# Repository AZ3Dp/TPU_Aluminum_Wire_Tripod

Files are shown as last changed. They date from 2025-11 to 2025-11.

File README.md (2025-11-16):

# FLEXPOD
#### TPU X ALU Wire Tripod
>By Aaron Zhan

Hello there! Thanks for stopping by!
## Introduction
I am a maker, 3D printer, inventor, and creative film-maker! 
(Though you can say those are a bit of a stretch, as I am learning new things almost every day). 
I tend to film Youtube videos with my phone, 
but I have always struggled to have a good yet simple camera/tripod setup. Mounting 
a camera is a struggle for anyone trying to take photos or videos (newbies and pros alike).
The main problem with tripods are that they aren't _flexible_ as int he sense that you can only use them in flat surfaces
and it is quite a hassle to adjust and set up (turning knobs, etc)
Luckily, the Gorilla Pod was invented. The Gorilla Pod (and other designs) feature 3 or more flexible
legs that can flex and adapt to the surface/object the tripod is to be mounted onto.
They are great products, and they are quite a hit!
However, if you are a fellew 3D printer, you would instantly have the instrusive thought of: "Can I 3D print that?"

Well, I tried that. And it went South. Some issues experienced with the Official Gorrila Pod was expereinced: 
the friction between the articulated links would gradually wear down. This would happen even whith the TPU bands around the links.
Well, there are variants of the gorilla pod where the legs are made out of 3 pieces of continuous metal that is flexible yet rigid
This design seldom loses its strength and thius its effectiveness. 
And with some inspiration from Reddit, I decided to make the tripod.
## Design Inspiration
So I had found a 3D printed Gorilla Pod design from My Mini Factory. It was honestly quite a clever design, taking great inspiration from the Original Gorilla Pid. It uses 3D printed segments in hard plastic (PLA, PETG, or ABS) and used some TPU connection parts (as "rubber bands" to connect and clamp down on the ball joints).
Again, worked _decently_, but after some extended use, the friction between the joints would wear down.
Luckily, I saw a reddit post: https://www.reddit.com/r/BambuLab/comments/1m8kska/aluminum_wire_in_tpu_is_my_new_favourite_thing_to/
and that gave me a lot of inspiration. I immediately saw some great insight in their design, and I thought I could make something amazing (even better) out of it. The designs mentioned in the Reddit post included many different uses, but being a content creator, I got excited at the sight of a tripod.
The Reddit user mentioned that 5mm craft wire was quite strong and flexible, so that's what I decided to go with. The Reddit user
also mentioned that stacking thin rectangular craft wires didn't cut it - it was too flimsy. This was perfect insight for me, since I didn't have to 
experiment with the different types of wire. The Reddit User's design uses a TPU print and embedding the wire into the TPU print. This is a clever 
way to accomplish the task, but it poses some problems that I identified: 1) The Aluminum Wire is not always straight and tidy, so embedding in the print may be
hard to accomplish and 2) If you want to remove the aluminum wire or swap it out for some reason, you'll have to destroy the TPU print. Embedding in the middle of the print job
is quite a hassle - bad for automation and user experience.
Screenshot 2025-11-09 at 11 44 03 AM
> The slits and 5mm hole enable a smooth experience when inserting and flexing the Aluminum Wire

## Design Innovation
And that's how my design was inspired and improved upon. FlexPod features easy-to-use TPU legs where you simply slide in the Aluminum Craft Wire (5mm, and generous tolerances were added!). This removes the hassle of pausing a print, making the process a whole lot easier! In addition, the leg takes advantage of the Pythagorean Theorem to be oriented on the build plate - you can get a 300mm long TPU leg out of a 220x200mm build plate! Some future plans include making an even longer TPU sleeve - possible oriented in a spiral - for those that need extra long tripod legs. The TPU 3D printed sleeves feature a repeating "slit" pattern, which alleviates stress and enables the TPU to be more flexible (and comply with the bending Aluminum Wire). These slits also reduce friction, enhancing the assembly process. For mounting, I included a simple m5 screw that is secured from the underside of the tripod. I know that people may have different variations of screws available, so the .f3d and .step files are included! m3 screws are used to mount the legs onto the base. The simplicity of the design is good to note! As for the model, I created a phone clamp that was remixed from a popular (and in my opinion, the best) phone clamp: https://www.printables.com/model/25969-tripod-mobile-phone-clamp-v2
Screenshot 2025-11-08 at 9 48 06 AM
> TinkerCAD is (sometimes) better than Fusion at _simple_ tasks!

###### lol a remix of a remix
So I simply took the base of that model, and combined it with the "base" of my Tripod in TinkerCAD (TinkerCAD is better at doing simple operations on STLs - you can do this in Slicer software as well).

## Materials Needed
I know there is a BOM, but this is probably more helpful
- Aluminum Wire
- m5 nuts and screws
- m3 nuts and screws
- TPU & PLA (or other rigid filament) for 3D printing

## Assembly and Manufacturing
FlexPod only has 5-7 printed parts in total (depending on how complicated the phone/camera/object mount is)
- 3 Legs: 95A (what I used, but more flexible is fine) TPU filament, 0.2mm (or finer) layer height, 2 perimeters, 15% infill
- Lower & Upper Base: PLA/ABS/PETG (rigid filament, PLA works fine), 0.2mm (or finer) layer height, 2 perimeters, 15% infill
- Mount (for camera, phone, etc): Make this as strong/weak as you want (depends on the application! For my phone clamp, I just used the same settings as above)

Assembly is pretty simple:
1) Insert the Aluminum Wire into the TPU sleeves, and use wire cutters to slowly (twisting the wire cutters for each cut) sever the Aluminum Wire
2) Prepare the bottom base: insert the m5 nut into the underside of the base. Screw in a m5 screw (I think m5x16 will do, depends on your application!) from the bottom
3) Insert m3 nuts into their respective slots on the bottom base. Fasten each leg to the base
4) Slide in a m5 nut into the Upper Base (or mount your subject onto the m5 screw!)

##Final Product
And that's it! Works decently well, but be careful of the Aluminum Wire sliding around a lot!
FlexPod
Access the project on Printables here: https://www.printables.com/model/1480173-flexpod-a-better-gorillapod-phone-tripod
Youtube video: https://youtube.com/shorts/_ZZmN3UGOKQ?feature=share

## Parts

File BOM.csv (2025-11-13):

Name | Quantity | Price | Link
Aluminum Craft Wire (5mm Diameter) | 1 | $20 | https://amzn.to/4qThZsJ

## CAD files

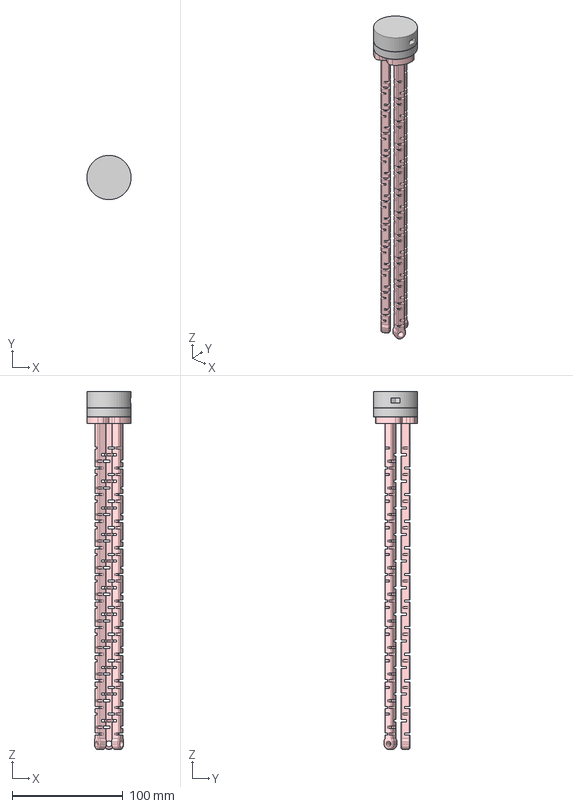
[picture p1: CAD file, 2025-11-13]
Assembly/FlexpodV1.step
40.0 x 40.0 x 323.0 mm
Base
FlexPod Leg x 3
Base 2

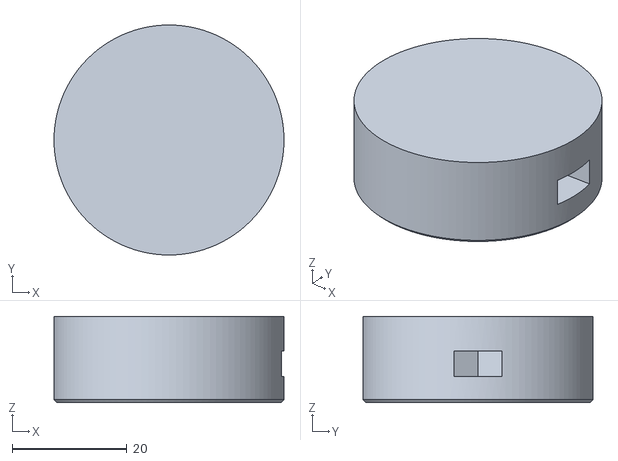
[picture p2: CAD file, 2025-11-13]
Mounts/Mount.stl
40.0 x 40.0 x 15.0

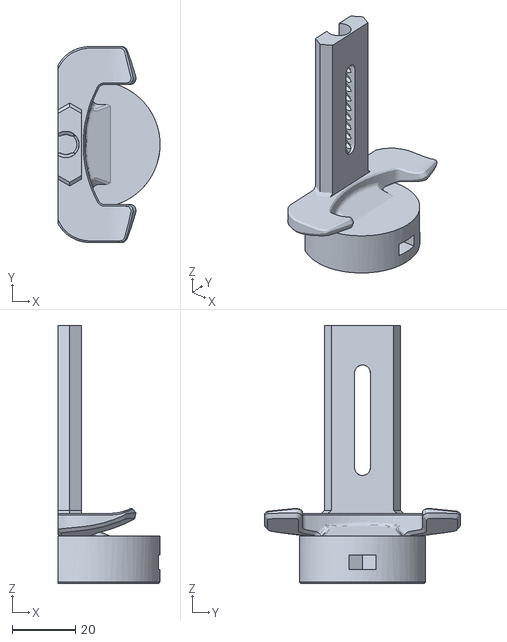
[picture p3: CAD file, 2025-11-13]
Mounts/Phone-Clamp-TPUALU.stl
32.4 x 62.0 x 81.7

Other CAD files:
Assembly/FlexpodV1.f3z

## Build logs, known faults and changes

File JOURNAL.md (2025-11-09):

<!--
  ===================    !!READ THIS NOTICE!!   ====================
  DO NOT edit this file manually. Your changes WILL BE OVERWRITTEN!
  This journal is auto generated and updated by Hack Club Blueprint.
  To edit this file, please edit your journal entries on Blueprint.
  ==================================================================
-->

## 10/23/2025 9 AM - Inspiration and Research (and material acquisition)  

Screenshot 2025-10-23 at 9.32.09 AM.png
I was scrolling through reddit and I came across an inspiring post where the OP used TPU and Aluminum wire. The OP created many cool projects like tripods, helping-hands, and other cool contraptions. The process incorporated pausing the print and embedding aluminum wire in the TPU print. I am thinking of expanding on this idea:

- Create slots so that aluminum wire doesn't need to be added in the middle of a print pause
- Create useful mounts, adaptable and modular
This project seems to have died down on the internet, so I am seeking to bring it back to life!

And I also researched and bought the materials:
95A TPU (already had)
5mm diameter aluminum craft wire
I have all of these supplies, so we should be ready to go!  

## 10/23/2025 2 PM - Created first TPU leg sleeve mockup CAD  

Screenshot 2025-10-23 at 2.22.13 PM.png
In this work session, I created the first version of the TPU leg. It is currently in a very basic form. Essentially, the TPU will form a sleeve around the Aluminum craft wire. I'm not sure if the TPU is too thick - we'll need to print it out to test it!  

## 10/23/2025 4 PM - CAD brush up and slice + first print  

[](
)
Made some small changes to the CAD model: added m3 mounting holes for the soon-to-be tripod. Definitely a nice print. Printed with Prusa Slicer and factory Prusa i3 mk3s+. The TPU came out fine, but it is really stiff (walls need to be a bit thinner). In addition, the hole sagged, so it is very hard to fit a 5mm aluminum wire in. Will need to make the changes in the next iteration!  

## 10/24/2025 - CAD Work  

Screenshot 2025-10-24 at 10.33.19 AM.png
Made a plethora of updates in CAD
New appearances: 

- Created a mounting system that will use heat set inserts for a modular mount. I aim for this to be compatible with phones, cameras, GoPros etc.
- The Tripod will use 3 legs (circular pattern)
Model updates/revisions:

- Added m5 mounting holes on the "ends" of the legs. This is for potentially mounting the tripod on aluminum extrusion.
- Reduced Wall thickness of TPU sleeve
- Added Chamfers and improved sagging by deleting circular overhangs.  

## 10/25/2025 1 PM - CAD brush up and slice + second print  




Today, I 3D printed out the new iteration of the tripod leg made out of TPU. The thinner walls definitely helped with flexibility, but it feels really weak and flimsy. In addition, the aluminum wire (5mm diameter) is having trouble being fully inserted. Will need to improve on this design!  

## 10/25/2025 10 PM - New Leg CAD design  

Screenshot 2025-10-25 at 10.19.58 PM
Screenshot 2025-10-25 at 10.20.43 PM
So a major problem with the previous design was the TPU being both inflexible and flimsy (this would be a tradeoff in a standard design). So, I added these cutouts along the TPU sleeve, which should in theory help with flexibility. This will also allow me to increase the wall thickness, without sacrificing flexibility. I also increased the size of the hole (increased tolerance), as well as optimized the model for 3D printing (horizantal bridges, instead of a circular bridge).

## 10/26/2025 - CAD brush up and slice + third print  


I 3D printed (sliced and printed with Prusa Slicer) the new leg sleeve design, and it’s safe to say that we are one step closer to the final product! The new sleeve is definitely stronger and more flexible than the previous iterations! The only downside I can think of is that the aluminum wire is partly exposed, which depending on your opinion, may be less aesthetically pleasing. I still wasn’t able to get the sleeve onto the wire - I’ll simply increase the tolerance in the next iteration. Super stoked!  

## 10/27/2025 - 3D print failure :(  


I made some revisions in CAD and sent it out to print in TPU. Nozzle clogged, probably due to bad filament. Only half of the model came out. I guess I’ll need to spend an hour or so fixing my printer :(  

## 10/30/2025 - It finally works! TPU sleeves fit in alu-wire!  


After a bunch of tweaking in CAD and slicer settings, I finally got the TPU leg sleeve to slide onto the Aluminum craft wire! Now, all I need to do is cut the wire into good lengths and make the camera mount, and we’lol have a final product!  

## 11/1/2025 - Assembled the Tripod Legs  


This was definitely harder than I expected. I wasn’t able to cut the thick aluminum craft wires at first with scissors or flush cutters. I later used a heavy duty wire cutter, and that worked. The strategy is to cut in a circle (like a beaver gnawing away at a tree) until the wire breaks. This will make a clean cut (if you try to cut it all in one go, the cut will be untidy)  

## 11/8/2025 9:35 AM - Created New Leg Base  

Screenshot 2025-11-08 at 9.32.23 AM

Today, I made a new leg mounting base that uses m3 nuts instead of headset inserts. This iteration is slightly simpler (and with better CAD practices) like using circular patterns instead of manually modeling each bore.  

## 11/8/2025 9:50 AM - Used TinkerCAD to create phone mount  

Screenshot 2025-11-08 at 9.48.06 AM
I used TinkerCAD (I know, sounds weird since I am always using Fusion) to combine a phone mount and the tripod. TinkerCAD, off of personal experience, is a lot better at handling STLs and simple procedures. I was able to quickly combine my two models, and now it's time to print!  

## 11/8/2025 8 PM - Manufacture and Assembly of first version  



I was able to print out and assemble the tripod for the first time! Had to play around with slicer settings and assembly went decently smooth. Used m5 connectors to connect the phone clamp and the tripod. The legs are a bit loose, so I need to reduce the “slits” towards the top of the leg. Also, the aluminum wire slides around, which is annoying, but it still works.  

## 11/9/2025 - Revising the Design  

Screenshot 2025-11-09 at 11.44.03 AM
As I said in the last journal, the connection near the top of the leg was too weak (unexpected bending), so I removed some "slits" towards the top of the leg. This should prevent weird bending and improve general stability.

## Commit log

2025-11-12 Enhance README with detailed introduction
    Expanded introduction with details about tripod challenges and 3D printing insights.
2025-11-12 Rename project from TPU X ALU Wire Tripod to FLEXPOD
2025-11-13 Add BOM.csv with initial product details
    [BOM.csv]
2025-11-13 Create instructions for FlexPod mounts
    Added introductory instructions for FlexPod mounts.
2025-11-13 Create instructions for FlexPod assembly updates
    Add instructions for FlexPod assembly files.
